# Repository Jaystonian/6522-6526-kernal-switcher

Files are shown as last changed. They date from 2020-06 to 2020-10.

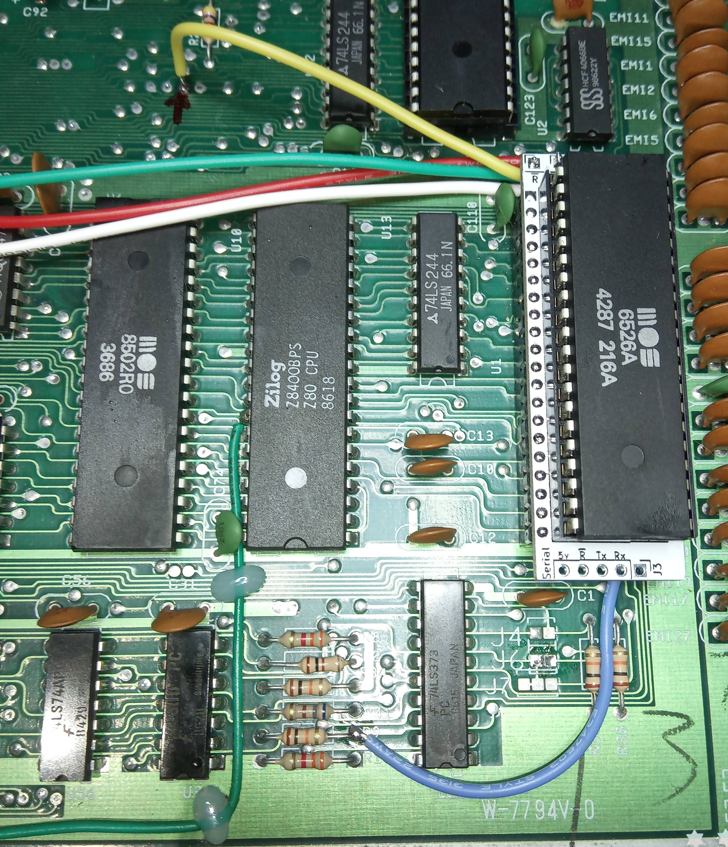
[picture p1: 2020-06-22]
docs/pics/c128_installed.jpg

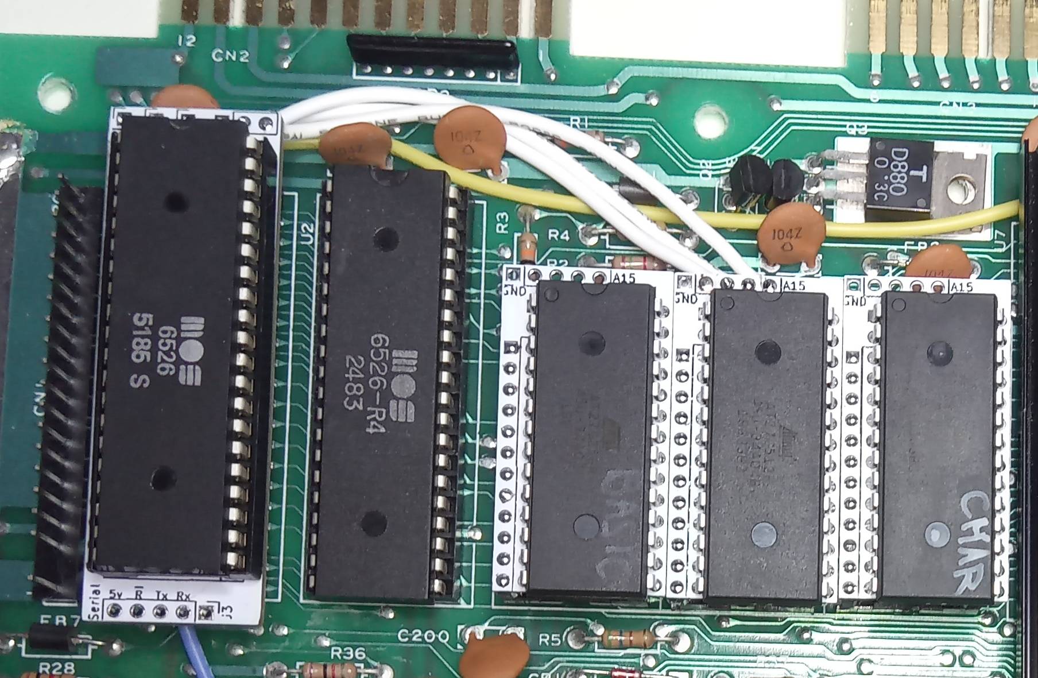
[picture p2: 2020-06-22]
docs/pics/c64_installed.jpg

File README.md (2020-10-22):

# 6522-6526-kernal-switcher
Adaptation of Sven Petersen's Keyboard Kernal Switch for MOS6522 or MOS6526 (VIC-20, C64, C128)

An ATMEGA328P microcontroller connected to the keyboard wires to listen for changes to keypresses 
of most of the top row of the keyboard. Hold down a number key and press RESTORE, (VIC-20 has 
limited compatibility) and three output bits (A B & C) for system control can be toggled by code.
The LED and bottom jumper can be wired directly (behind the resistor from the LED pin for example) 
and reprogrammed to use those as two extra output bits. Inputs can be reprogrammed to include + 
and - for example and then increase/decrease the selected output to control multiple EPROMs or 
devices for different reboot modes.  Memory controller modes, other ROMs, better control over more 
function roms in a C128 with more KERNAL ROMs (2 and 4 or 4 and 2 work well together with just ABC)
or memory maps etc.  With 5 you can dedicate 2 and 3 (giving 4 and 8 selections) instead of sharing 
lines as demonstrated in the C128 installation.

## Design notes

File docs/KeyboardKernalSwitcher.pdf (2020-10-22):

## Sven Petersen's C64-Keyboard-Controller-Kernal-Switch

https://github.com/svenpetersen1965/C64-Keyboard-Controlled-Kernal-Switch Jaystonian's 6522/6526 Version for VIC-20, C64, C128

I redesigned Sven's microcontroller board for higher compatibility. It originally only fit the C64 keyboard 20-SIP header connector, and some boards required other modifications. It resets the system after selecting different regions of an EPROM (such as the KERNAL) by selecting the higher address lines using the Restore key and a number. It also allows for “shortboard” eprom selecting, since
BASIC and KERNAL were combined in these models, with a solderjumper to tell the microcontroller.

It made sense to make it for the 40-DIP socket instead, so any system using the identical keyboard array can use the same switch. My idea is this can also be used to select configurations of the VIC-20's memory map, or different ROMs in different sockets on the C128 (KERNALs, BASICs, Internal EPROM socket). Also available on the C128 are data lines indicating 40/80 column mode and 64/128 mode. The 3 digital outputs of this switchboard provide a binary 0-7 (000-111, digital lines A, B and C). The solderjumper for shortboards in my design is called JP1, found on the bottom. I didn't include the JTAG connector or the full parts for the serial connection, although pins are exposed.

Please read and re-read instructions until steps are clear to you. Review the notes at the end of this document for advice on finding /RESTORE and /EXROM locations for your device model.

The six solder through-holes along the top end (between Pin 1 and Pin 40) are for /RESTORE, /EXROM, Power LED, and A B C. The serial connection straddles Pin 20 and Pin 21 (lower end); pins are 5V, /RESET, Tx, Rx and GND, respectively. Pin 1 (square pad) is GND. For the JTAG, 5V /RESET and GND are shared from serial, while MISO MOSI and SCK (respectively) are exposed as solderpads on the bottom, with MISO closest to Pin 40. For the most part, you will never need these.

We can use line A connected to the highest address line of a 27128 (16kb eprom) to select low/high 8kb for standard kernal or another, or the highest address line of a 27256 (32kb) for low/high 16kb regions. Or A and B for four, or A B C for eight. Hopefully this is not new information. This leads to multiple EPROMs, where C can be a low/high for the “Internal” socket, and A and B for kernal socket(s), and B for basic socket(s). This can provide a wider range of options for selecting EPROM regions.

For the more talented, you may choose to implement a selector circuit to configure eight completely different modes of any configuration for multiple EPROMs, enable memory expansions, toggle CPU speed... your imagination is the limit!

TOOLS NEEDED:
– Soldering iron
– Wire stripper (or whatever tool you are comfortable doing this with, without damaging the wire)
– Wire cutters
– Digital Multi Meter (DMM) or continuity tester

CONSUMABLES
– Solder and flux
– Some wire, 20ga to 26ga should be fine, solid or stranded, copper or not, shielded or not, but insulated always. If shielded, then be sure to ground the shielding and that it is not electrically connected.

INSTALLATION

1. Identify and locate the MOS 6522 or MOS 6526 40-pin IC chip responsible for your keyboard. This is typically U1 in 64/128, UAB1 or UDE8 (E) or UAB3 (CR) in VIC-20.
2. If this IC is not socketed, please de-solder it and then install a socket.
3. If you are installing this in a C64 shortboard (Rev 250469), then solder closed JP1 on the bottom. This is /SHORTBRD input in Sven's PDF, aka solderjumper “CP1”.
4. Locate the /RESTORE line on the motherboard and its distance to Pin 1 of the keyboard IC socket and then cut a wire long enough to reach, giving you an extra inch or two to trim later if necessary. Trim 1/8-inch of insulation from the wire and solder to the top-left through-hole of the switchboard.
5. Locate the /EXROM line on the motherboard and do the same as step 3 above, cutting a wire long enough, trim, then solder to the through-hole next to /RESTORE. This can be omitted on the VIC-20.
6. Optionally you may wire the Power LED directly to the third hole (anode of LED), which is current-limited by a 330-Ohm resistor on board, and then ground the LED's cathode. The switcher will flash this LED depending on modes. This is called RESIO in Sven's PDF.
7. The last three holes, which fits a 1x03 0.1” pitch (2.54mm) header, are A B C. For most users, you will have a single EPROM and ABC will go to A13, A14 and A15 of a 27512 for selecting one of eight 8KB regions, or you will be using shortboard mode (please review Sven's documentation for this). Or A15, A16 and A17 for 32KB regions of a 27c020 in a 32-pin socket. Or use your imagination!
8. Install switch board into socket with respect to “Pin 1 notch”, do not install backwards. The board has a socket with a notch on one end which should match the location of the socket notch underneath. Ensure your soldered wires do not contact anything else connected to the motherboard.
9. Solder /RESTORE and /EXROM wires to their respective locations on the motherboard. Ensure they are not soldered to more than one pin or location (resistor legs, vias, etc) and trim them short.
10. Install the 6522 or 6526 IC on top of the switch board, paying attention to the location of the Pin 1 notch.

USAGE

Please review Sven's original documentation. However, I will summarize:

While computer is ON...

– Holding RESTORE key for 1.5 to 3.0 seconds, you get a NORMAL RESET.
– Holding RESTORE ket for longer than 3.0 seconds, UNSTOPPABLE RESET.
– RESTORE + 0 selects 000 KERNAL and disables the scanning for improved compatibility (for diagnostic cartridges, for example)
– RESTORE + # (ie., 1 to 8, or 1 to 7 in shortboards) selects 000 to 111 KERNAL

NOTES

- VIC-20:
– /RESTORE can be found as the north leg of R1, south of U1 (whichever is not 5V)
– /EXROM does not exist, omit connection.
– Some of the number keys do not respond with the restore-reset and the ones that do just tend to randomly toggle the outputs and succeed a reset. No troubles if just switching two ROMs.
- VIC-20E:
– /RESTORE can be found as the north leg of R26, west of UD6
– /EXROM does not exist, omit connection.
- VIC-20CR:
– /RESTORE can be found as R16 south of the keyboard header. You will need to continuity test to find which leg, from Pin 3 of the keyboard header.
– /EXROM does not exist, omit connection.
- C64 Rev326298:
– /RESTORE can be found as the east leg of R41, along the west side of the board.
– /EXROM can be found on Pin 23 of U17. Continuity exploration recommended for a nearby through-hole between U17 and the SID chip.

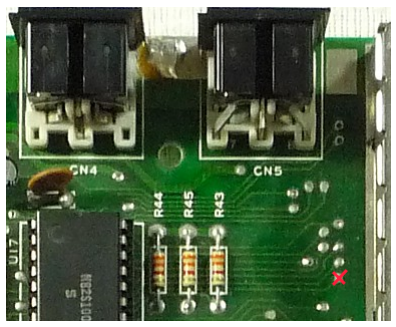
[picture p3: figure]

- C64 Rev250407:
– /RESTORE can be found as the east leg of R41, near the lower left corner of the board.
– /EXROM can be found south of the A/V Port, next to the RFM shield.

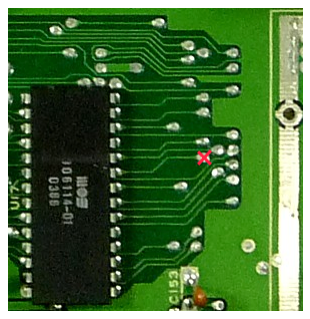
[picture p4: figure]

- C64 Rev250425:
– /RESTORE can be found as the east leg of R41, near the bottom-left corner of the board.
– /EXROM can be found right of U17

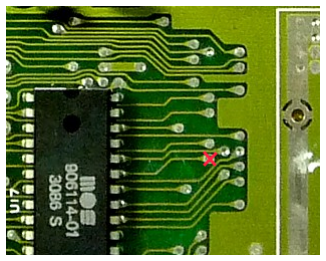
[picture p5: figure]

- C64 Rev250466:
– /RESTORE can be found as the east leg of R41, near the lower left corner of the board.
– /EXROM can be found east of U17
- C64 Rev250469:
– /RESTORE can be found immediately to the right of Keyboard Header pin 3.
– /EXROM can be found west of the RFM
- C128, 128D:

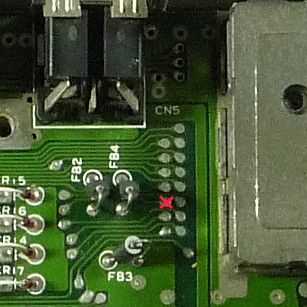
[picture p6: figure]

– /RESTORE is nearby U1, either immediately south near its Pin 21 (which would be beneath the installed switchboard), or the east leg of R9.
– /EXROM is to the left of U7, about 1/4-inch (~6mm) southwest of R27.

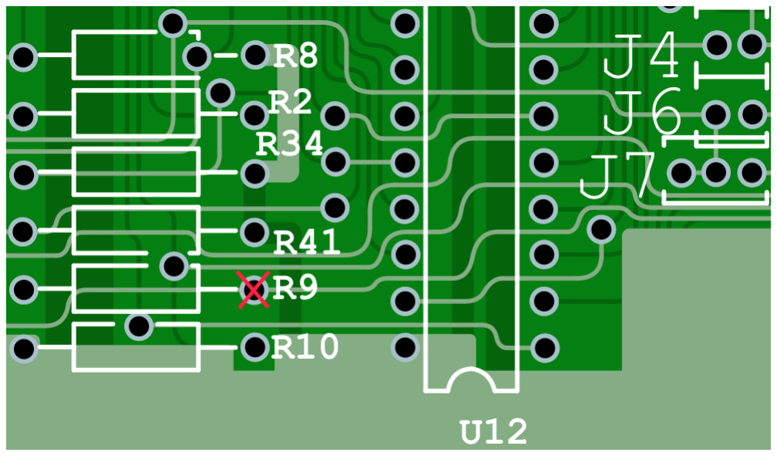
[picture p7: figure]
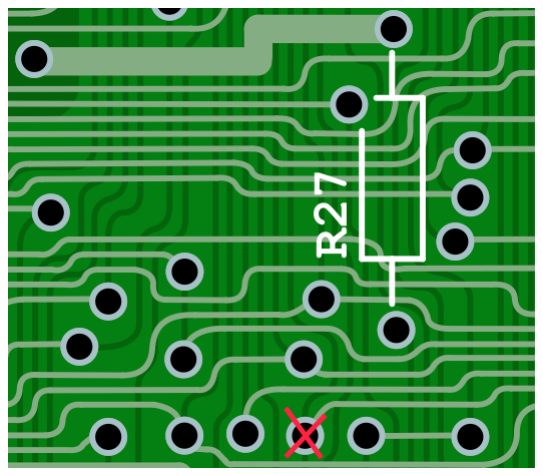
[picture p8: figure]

- C128DCR: There are several revisions of this Cost Reduced model. I have an earlier model that is a “full-size board.” The simplest way for you to find exposed through-holes, instead of IC legs, is with a continuity tester using the leg pin as a starting point and then explore.
– /RESTORE can be found on Pin 9 of U16
– /EXROM can be found on Pin 46 of U7

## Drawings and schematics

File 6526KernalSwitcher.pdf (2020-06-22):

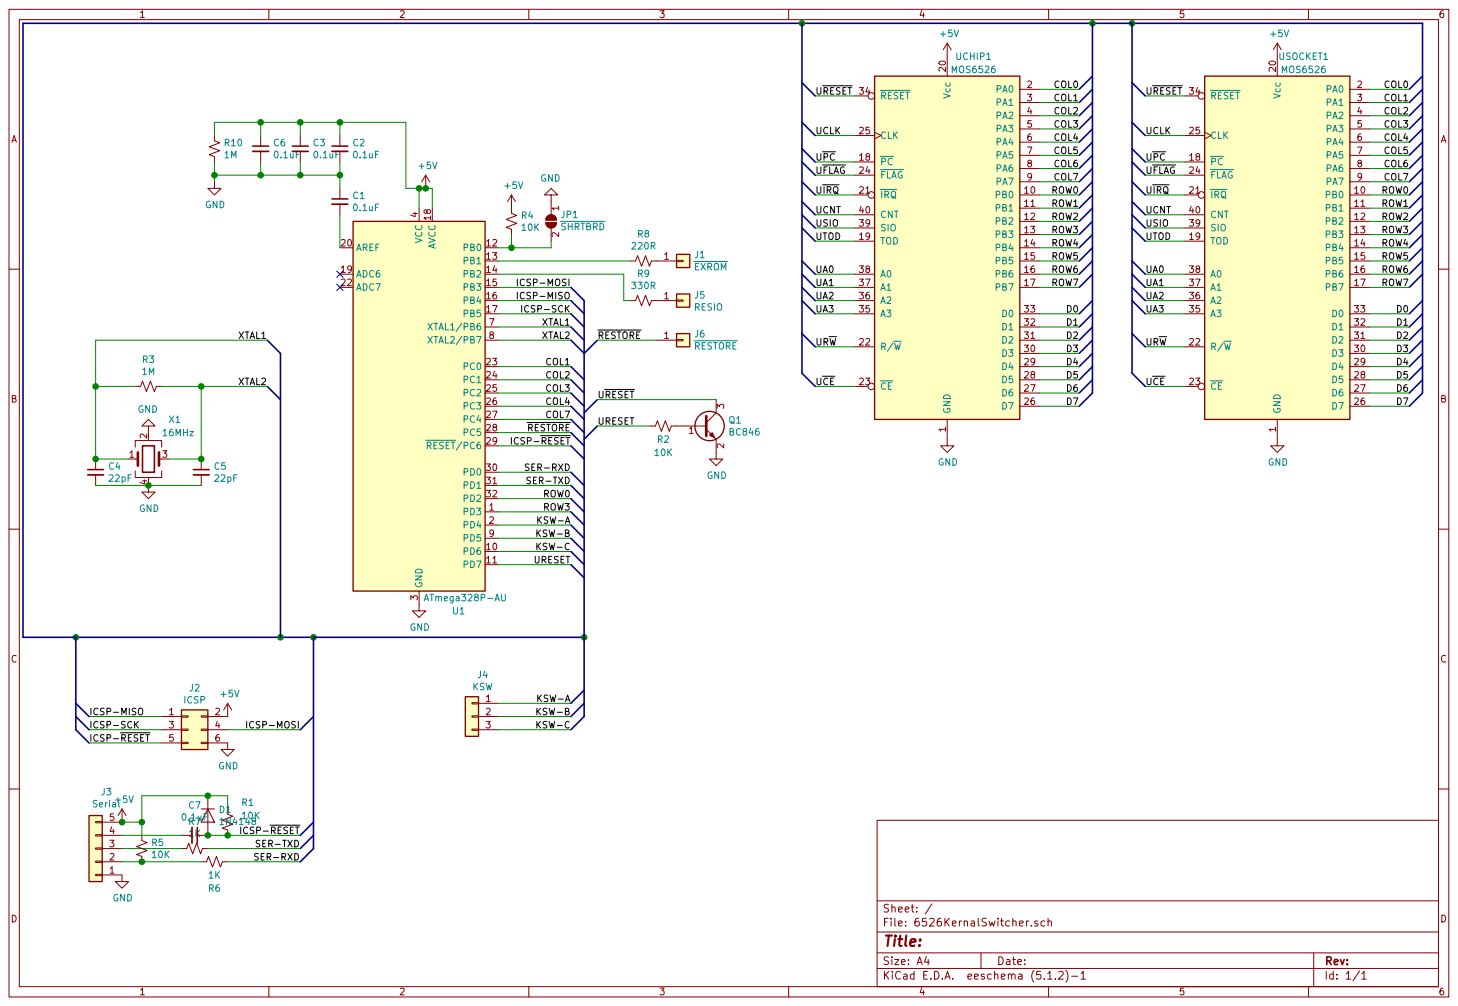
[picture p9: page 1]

ICSP-RESET SER-TXD

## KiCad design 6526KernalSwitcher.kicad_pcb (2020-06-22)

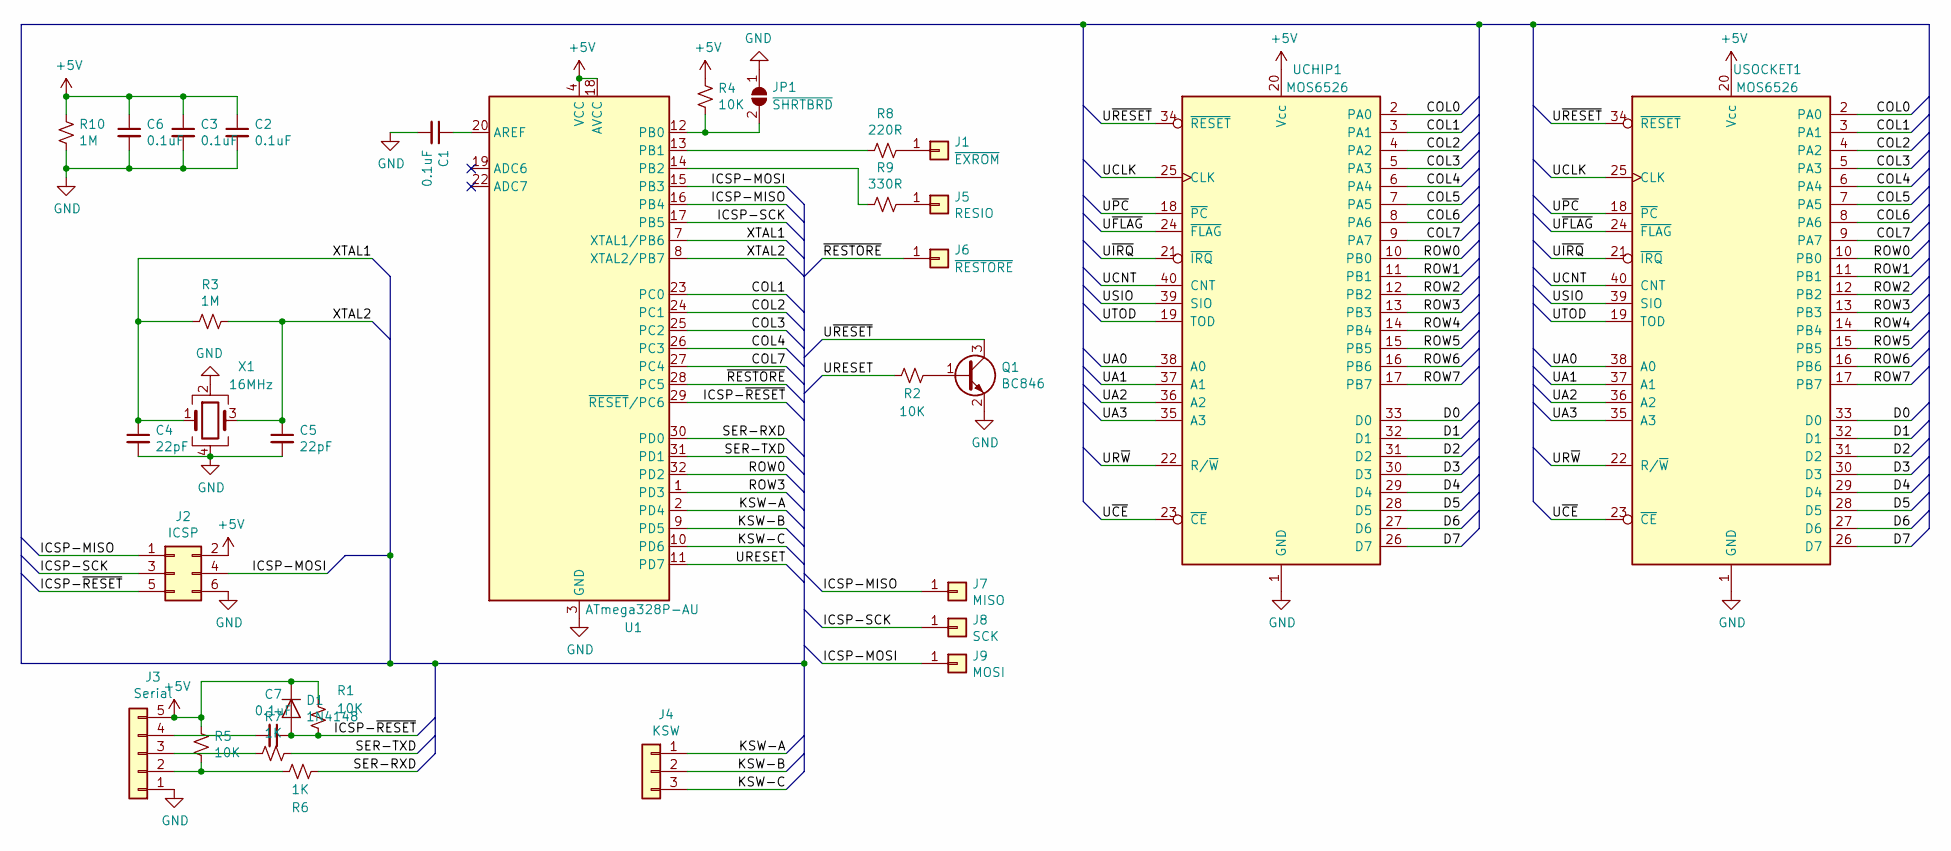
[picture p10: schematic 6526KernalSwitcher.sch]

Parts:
C1, C2, C3, C6, C7: 0.1uF; C_0805_2012Metric_Pad1.15x1.40mm_HandSolder
C4, C5: 22pF; C_0805_2012Metric_Pad1.15x1.40mm_HandSolder
D1: 1N4148; D_MiniMELF
J1: ~EXROM; PinHeader_1x01_P2.54mm_Vertical
J2: ICSP; PinHeader_2x03_P2.54mm_Vertical
J3: Serial; PinHeader_1x05_P2.54mm_Vertical
J4: KSW; PinHeader_1x03_P2.54mm_Vertical
J5: RESIO; PinHeader_1x01_P2.54mm_Vertical
J6: ~RESTORE; PinHeader_1x01_P2.54mm_Vertical
J7: MISO; SolderPad
J8: SCK; SolderPad
J9: MOSI; SolderPad
JP1: ~SHRTBRD; SolderJumper-2_P1.3mm_Open_RoundedPad1.0x1.5mm
Q1: BC846; SOT-23
R1, R2, R4, R5: 10K; R_0805_2012Metric_Pad1.15x1.40mm_HandSolder
R3, R10: 1M; R_0805_2012Metric_Pad1.15x1.40mm_HandSolder
R6, R7: 1K; R_0805_2012Metric_Pad1.15x1.40mm_HandSolder
R8: 220R; R_0805_2012Metric_Pad1.15x1.40mm_HandSolder
R9: 330R; R_0805_2012Metric_Pad1.15x1.40mm_HandSolder
U1: ATmega328P-AU; TQFP-32_7x7mm_P0.8mm
UCHIP1: MOS6526; DIP-40_W15.24mm
USOCKET1: MOS6526; DIP-40_W15.24mm
X1: 16MHz; Crystal_SMD_2016-4Pin_2.0x1.6mm

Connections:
+5V: C2.1, C3.1, C6.1, D1.1 (K), J2.2, J3.5, R1.1, R4.1, R5.1, R10.1, U1.4 (VCC), U1.6 (VCC), U1.18 (AVCC), UCHIP1.20 (Vcc), USOCKET1.20 (Vcc)
/COL0: UCHIP1.2 (PA0), USOCKET1.2 (PA0)
/COL1: U1.23 (PC0), UCHIP1.3 (PA1), USOCKET1.3 (PA1)
/COL2: U1.24 (PC1), UCHIP1.4 (PA2), USOCKET1.4 (PA2)
/COL3: U1.25 (PC2), UCHIP1.5 (PA3), USOCKET1.5 (PA3)
/COL4: U1.26 (PC3), UCHIP1.6 (PA4), USOCKET1.6 (PA4)
/COL5: UCHIP1.7 (PA5), USOCKET1.7 (PA5)
/COL6: UCHIP1.8 (PA6), USOCKET1.8 (PA6)
/COL7: U1.27 (PC4), UCHIP1.9 (PA7), USOCKET1.9 (PA7)
/D0: UCHIP1.33 (D0), USOCKET1.33 (D0)
/D1: UCHIP1.32 (D1), USOCKET1.32 (D1)
/D2: UCHIP1.31 (D2), USOCKET1.31 (D2)
/D3: UCHIP1.30 (D3), USOCKET1.30 (D3)
/D4: UCHIP1.29 (D4), USOCKET1.29 (D4)
/D5: UCHIP1.28 (D5), USOCKET1.28 (D5)
/D6: UCHIP1.27 (D6), USOCKET1.27 (D6)
/D7: UCHIP1.26 (D7), USOCKET1.26 (D7)
/ICSP-MISO: J2.1, J7.1, U1.16 (PB4)
/ICSP-MOSI: J2.4, J9.1, U1.15 (PB3)
/ICSP-SCK: J2.3, J8.1, U1.17 (PB5)
/ICSP-~RESET: C7.1, D1.2 (A), J2.5, R1.2, U1.29 (~RESET~/PC6)
/KSW-A: J4.1, U1.2 (PD4)
/KSW-B: J4.2, U1.9 (PD5)
/KSW-C: J4.3, U1.10 (PD6)
/ROW0: U1.32 (PD2), UCHIP1.10 (PB0), USOCKET1.10 (PB0)
/ROW1: UCHIP1.11 (PB1), USOCKET1.11 (PB1)
/ROW2: UCHIP1.12 (PB2), USOCKET1.12 (PB2)
/ROW3: U1.1 (PD3), UCHIP1.13 (PB3), USOCKET1.13 (PB3)
/ROW4: UCHIP1.14 (PB4), USOCKET1.14 (PB4)
/ROW5: UCHIP1.15 (PB5), USOCKET1.15 (PB5)
/ROW6: UCHIP1.16 (PB6), USOCKET1.16 (PB6)
/ROW7: UCHIP1.17 (PB7), USOCKET1.17 (PB7)
/SER-RXD: R6.1, U1.30 (PD0)
/SER-TXD: R7.1, U1.31 (PD1)
/UA0: UCHIP1.38 (A0), USOCKET1.38 (A0)
/UA1: UCHIP1.37 (A1), USOCKET1.37 (A1)
/UA2: UCHIP1.36 (A2), USOCKET1.36 (A2)
/UA3: UCHIP1.35 (A3), USOCKET1.35 (A3)
/UCLK: UCHIP1.25 (CLK), USOCKET1.25 (CLK)
/UCNT: UCHIP1.40 (CNT), USOCKET1.40 (CNT)
/URESET: R2.2, U1.11 (PD7)
/UR~W: UCHIP1.22 (R/~W~), USOCKET1.22 (R/~W~)
/USIO: UCHIP1.39 (SIO), USOCKET1.39 (SIO)
/UTOD: UCHIP1.19 (TOD), USOCKET1.19 (TOD)
/U~CE: UCHIP1.23 (~CE~), USOCKET1.23 (~CE~)
/U~FLAG: UCHIP1.24 (~FLAG~), USOCKET1.24 (~FLAG~)
/U~IRQ: UCHIP1.21 (~IRQ~), USOCKET1.21 (~IRQ~)
/U~PC: UCHIP1.18 (~PC~), USOCKET1.18 (~PC~)
/U~RESET: Q1.3 (C), UCHIP1.34 (~RESET~), USOCKET1.34 (~RESET~)
/XTAL1: C4.1, R3.2, U1.7 (XTAL1/PB6), X1.1
/XTAL2: C5.1, R3.1, U1.8 (XTAL2/PB7), X1.3
/~RESTORE: J6.1, U1.28 (PC5)
GND: C1.2, C2.2, C3.2, C4.2, C5.2, C6.2, J2.6, J3.1, JP1.1 (A), Q1.2 (E), R10.2, U1.3 (GND), U1.5 (GND), U1.21 (GND), UCHIP1.1 (GND), USOCKET1.1 (GND), X1.2, X1.4
unnamed: C1.1, U1.20 (AREF)
unnamed: C7.2, J3.4
unnamed: J1.1, R8.1
unnamed: J3.2, R5.2, R6.2
unnamed: J3.3, R7.2
unnamed: J5.1, R9.1
unnamed: JP1.2 (B), R4.2, U1.12 (PB0)
unnamed: Q1.1 (B), R2.1
unnamed: R8.2, U1.13 (PB1)
unnamed: R9.2, U1.14 (PB2)

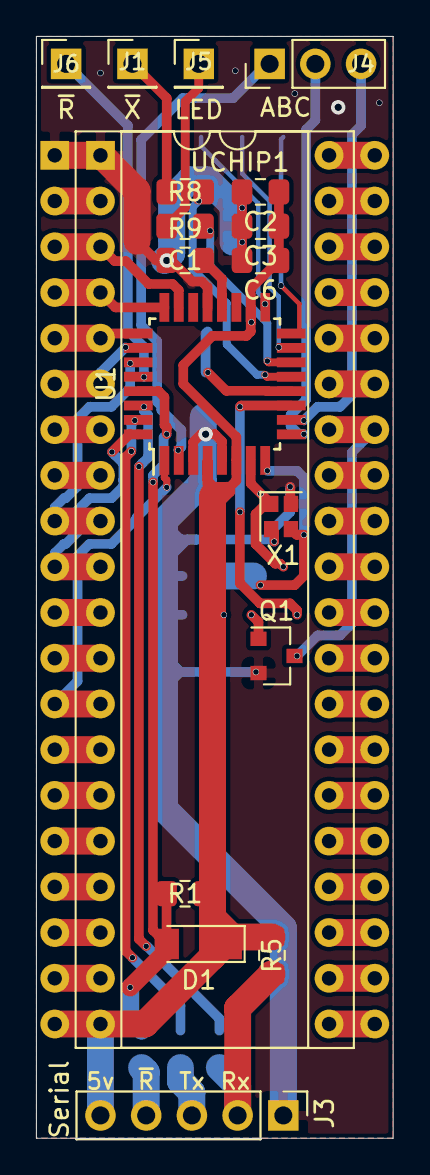
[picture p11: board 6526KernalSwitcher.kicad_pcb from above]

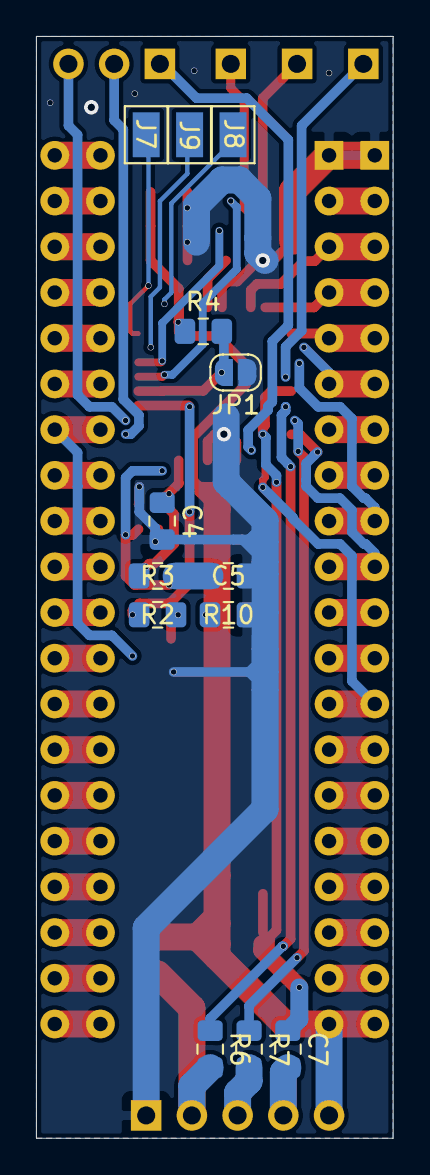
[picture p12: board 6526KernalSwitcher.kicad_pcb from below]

Board: 2 copper layers, 19.8 x 61.2 mm, 32 parts (13 on the bottom side), 63 nets.

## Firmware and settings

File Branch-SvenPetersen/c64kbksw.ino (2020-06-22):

/*  Software for the keyboard controlled kernal switch
 *  by Sven Petersen, 2020
 *  
 *  Revisioon history 
 *  Rev. 0.0: initial release
 *  Rev. 0.1: since some games (e.g. Gyruss) modify the reset procedure, the "unstoppable reset" (= EXROM Reset) was 
 *            implemented. Pressing RESTORE for approximatety 2-4 seconds is a normal reset, holding it longer =  
 *            EXROM reset.
 *  Rev. 0.2: Implemented signalling on RESIO2.          
 */

#define LED
//#define buzzer

#include <EEPROM.h>

/* Configuration */
const bool recover_empty = true;     //enable recover to Kernal one, in case an empty/not working kernal was selected
const int  NumKernal = 8;            //This is the highest valid Kernal number
 
/* pin definitions */
const int row0 = 2;         // Row signal, input, active low, INT0
const int row3 = 3;         // Row signal, input, active low, INT1
const int KSW_A13 = 4;      // output, A13 to kernal adaptor/switch
const int KSW_A14 = 5;      // output, A14 to kernal adaptor/switch
const int KSW_A15 = 6;      // output, A15 to kernal adaptor/switch
const int C64RESET = 7;     // output, RESET signal for the C64
const int col1 = A0;        // input, column signal, active low
const int col2 = A1;        // input, column signal, active low
const int col3 = A2;        // input, column signal, active low
const int col4 = A3;        // input, column signal, active low
const int col7 = A4;        // input, column signal, active low
const int nRESTORE = A5;    // input, RESTORE key, active low
const int nSHORT_BRD = 8;   // input, short board jumper
const int nEXROM = 9;       // /EXROM Pin connected to pin header J4, pin 5 
// const int RSVD  = 10;    // reserved. Pin connected to pin header J4, pin 6
const int Signalling  = 10; // Pin for signaling (LED or buzzer with tone generator), pin header J4, pin 6

#ifdef buzzer
const bool sig_idle = LOW;   // idle level of J4, pin 6 (should be HIGH for a power LED) 
#else
const bool sig_idle = HIGH;  // idle level of J4, pin 6 (should be HIGH for a power LED)
#endif 

const int Restore_Count = 1500; // count appr. 2 seconds for RestoreKey before Reset
const int EXROM_Count = 3000;   // limit for EXROM reset
const int Sig_time = 500; // constant for signalling duration

/* other constants */
#define EEPROMAddr 0        // EEPROM Address of last kernal selection
#define ScanDelay 10000     // delay ibn ms before reset for no scan activity or an empty kernal memory slot, respectively

/* variables */
byte KOffset = 0;           // offset for kernal number
byte KNumber = 0;           // Kernal number
byte KAddr = 0;             // Address bits for Kernal
bool RestoreKey = 0;        // holds the info, if the restore key is pressed 
bool oldRestoreKey = 0;     // remeber the old status to compare
int  countup = 0;           // counter for restore key time measurement
byte key = 128;             // calculate the Key
int  KMax;                  // holds the highest Kernal Number


/* Data Exchange variables for ISR (have to be volatile) */
volatile bool NumPressed = 0;  // ISR flag for number pressed
volatile bool NumOdd = 0;      // ISR flag for odd numbers. Row0 => odd numbers, Row3 => even numbers
volatile byte ColData = 0x1F;  // column data, read from PORTD

/* in case, the kernal switch switches to a memory slot without a proper kernal software
 *  there is no keyboard scan activity. That is why the kernal switch cannot detect keys anymore
 *  to circumvent this, the column scan activity is detected. If there is no activity after switching kernals
 *  the kernal is set to #1 and the C64 is reset.
 */
byte columns;           // variable for reading out the column
int scan_cnt;           // 5000 miliseconds without scan changing to kernal #1 and resetting
int scan_found;         // flag for keybioard activity detected
byte inactive = 0;      // keyboard scan inactive: 1 -> inactive, 0 = active
bool exrom_mode = 0;    // exrom reset: 0 => no, 1 => yes
int signalling_cnt = 0; // count down for signalling pin

void setup() {
  /* keyboard scan signals */
  pinMode( row0, INPUT_PULLUP);  // pullup required for MOS logic
  pinMode( row3, INPUT_PULLUP);  // pullup required for MOS logic
  pinMode( col1, INPUT_PULLUP);  // pullup required for MOS logic
  pinMode( col2, INPUT_PULLUP);  // pullup required for MOS logic
  pinMode( col3, INPUT_PULLUP);  // pullup required for MOS logic
  pinMode( col4, INPUT_PULLUP);  // pullup required for MOS logic
  pinMode( col7, INPUT_PULLUP);  // pullup required for MOS logic
  pinMode( nRESTORE, INPUT_PULLUP);  // pullup required for MOS logic
  pinMode( nEXROM, INPUT );      // it needs to be high impedance, will switch to LOW and OUTPUT when required.
  digitalWrite( nEXROM, HIGH );
  digitalWrite( Signalling, sig_idle ); // Signalling pin6, J4
  pinMode( Signalling, OUTPUT);

  /* jumper */
  pinMode(nSHORT_BRD, INPUT);   // jumper: LOW = Short Board => lowest kernal number is 1
  if (digitalRead(nSHORT_BRD) == LOW)
  { 
    KOffset = 1; // it is a short board! kernal number offset is 1, since the BASIC is in the lowest 8k of the Kernal ROM
  }

  /* last kernal from eeprom */
  KNumber = EEPROM.read(EEPROMAddr);
  if ((KNumber < 1) || (KNumber > 8-KOffset)) { // if out of range, the first kernal is selected.
    KNumber = 1;
    EEPROM.write(EEPROMAddr, KNumber);
  }
  inactive = EEPROM.read(EEPROMAddr+1);         // keyscan inactive flag
  if (inactive > 1) {
    inactive = 0;
    EEPROM.write(EEPROMAddr+1, inactive);
  }
  exrom_mode = 0;                               // initialize exrom mode (for reset). 0 = no exrom reset
  
  KAddr = KNumber - 1 + KOffset; // Calculate the address bits.
  // For long boards, it should be between 0 and 7,
  // for short boards, it should be 1 to 7, because the first 8k are occupied by the BASIC ROM. 
  
  /* Control outputs (for Kernal Adaptor and C64) */
  SetAddressBits( KAddr );        // set the MS address bits for the kernal ROM
  pinMode( KSW_A13, OUTPUT );     // make it an output   
  pinMode( KSW_A14, OUTPUT );     // make it an output
  pinMode( KSW_A15, OUTPUT );     // make it an output
  digitalWrite( C64RESET, LOW );  // no reset for the C64
  pinMode( C64RESET, OUTPUT );    // make it an output

  if (recover_empty == true) {
    scan_cnt = ScanDelay;         // reset scan countdown
    scan_found = false;           // reset detection flag 
    KMax = 8 - KOffset; 
  }
  else {
    scan_cnt = 0;                 // reset scan countdown
    scan_found = true;            // reset detection flag
    KMax = NumKernal;
  }
  if (inactive == 1) {             // if scan timeout is inactive, just set scan_found
    scan_found = true;
    scan_cnt = 0;
  }
      
  attachInterrupt(digitalPinToInterrupt(row0), ISR_row0, LOW); 
  attachInterrupt(digitalPinToInterrupt(row3), ISR_row3, LOW);
  
  Serial.begin(9600);  // start serial interface
  /* output status etc. */
  Serial.println( "\nC64 Keyboard Controlled Kernal Switch v0.20" );
  if (KOffset == 1) {
    Serial.println("Short Board configured.");
  }
  else {
    Serial.println("Long Board configured.");
  }
  if (recover_empty == true) {
    Serial.print("Empty Kernal slot (=scan activity) detection: ");
    if (inactive == 1 ) {
      Serial.println("inactive.");
    }
    else {
      Serial.println("active.");
    }
  }
  else {
    Serial.print("Number of Kernals: ");
    Serial.println(NumKernal);
  }
  Serial.print("Kernal number: ");
  Serial.println( KNumber );
}

/* This function sets the address bits on the pin header J4. Parameter is addr (0..7) */
void SetAddressBits( byte addr ) {
   digitalWrite( C64RESET, HIGH );                              // do it, while /reset is low (samle like the port pin is high)
   delay (50 );                                                 // wait 50 ms
   if ((addr & 1) == 0) {         // A13                  
    digitalWrite(KSW_A13, LOW);
  }
  else {
    digitalWrite(KSW_A13, HIGH);  
  }
  if ((addr & 2) == 0) {          // A14
    digitalWrite(KSW_A14, LOW);
  }
  else {
    digitalWrite(KSW_A14, HIGH);  
  }
  if ((addr & 4) == 0) {          // A15
    digitalWrite(KSW_A15, LOW);
  }
  else {
    digitalWrite(KSW_A15, HIGH);  
  }
}

void ResetC64() {
  digitalWrite( Signalling, !sig_idle );                     // Signalling active
  digitalWrite( C64RESET, HIGH );                            // issue a reset pulse for the C64
  delay( 100 );                                              // 100ms delay
  if (exrom_mode == 1) {
    digitalWrite( nEXROM, LOW );                             // exrom pin low
    pinMode( nEXROM, OUTPUT );                               // and output
  }
  delay( 300 );                                              // pulse duration: 100+300ms
  digitalWrite( C64RESET, LOW );
  if (exrom_mode == 1) {
    delay( 300 );                                            // EXROM should be 300ms longer LOW than RESET
    pinMode( nEXROM, INPUT );                                // and input = high impedance (HIZ)
    digitalWrite( nEXROM, HIGH );                            // exrom pin high
  }
  if ((recover_empty == true) && (inactive == 0)) {
    scan_cnt = ScanDelay;                                    // reset scan countdown
    scan_found = false;                                      // reset detection flag
  }  
  else {
    scan_cnt = 0;
    scan_found = true;
  }
  countup = 0;
  digitalWrite( Signalling, sig_idle );                      // Signalling inactive
}

void SwitchKernal() {
  digitalWrite( C64RESET, HIGH );                            // issue a reset pulse for the C64
  SetAddressBits( KAddr );                                   // set the address bits A15..A13
  Serial.print("Change to Kernal number: ");                 // send the status to serial
  Serial.println( KNumber );
  ResetC64();                                                // Reset the C64
  delay( 2000 );                                             // give some delay to release the RESTORE key
}

// Interrupt Service Routine for Row0
void ISR_row0() {
  if (NumPressed == 0) {                  // only process info, after the flag was reset by main routine
     ColData = PINC & 0x1F;               // read the columns
     scan_found = true;                   // any activity here indicates a working kernal
     NumOdd = 1;                          // row0 has the odd numbers
     if ((ColData != 0x1F) && (ColData !=0)) {               // only set the flag, when a number is pressed 
       NumPressed = 1;
     }  
  }
}

// Interrupt Service Routine for Row3
void ISR_row3 () {
  if (NumPressed == 0) {                  // only process info, after the flag was reset by main routine
     ColData = PINC & 0x1F;               // read the columns
     scan_found = true;                   // any activity here indicates a working kernal
     NumOdd = 0;                          // row3 has the even numbers
     if ((ColData != 0x1F) && (ColData !=0)) { // only set the flag, when a number is pressed 
       NumPressed = 1;
     }  
  }
}

void loop() {
  /* find the scan activity to make sure, the selected Kernal is working */
  if (scan_found == false) {                            // if not yet a scan activity is detected
    columns = PINC & 0x1F;                              // read the column data
    if ((columns != 0x1F)) {                            // activity found?
      scan_found = true;                                // set flag
      Serial.println( "Keyboard scan detected."); 
    }
    else {
      if (scan_cnt > 0) {                               // if the count down is not elapsed
        scan_cnt--;                                     // then decrement
        delayMicroseconds( 33 );
      }
      else {
        Serial.println( "No keyboard scan detected.");  // the count down is elapsed!
        KNumber = 1;                                    // Set Kernal Number 1 (it is assumed, that this is not empty)
        EEPROM.write(EEPROMAddr, KNumber);              // and save in EEPROM
        KAddr = KOffset;                                // Calculate the address bits.
        SwitchKernal();                                 // Switch Kernal Number and reset C64
      }
    }
  }
  
  /* process restore key */ 
  if (digitalRead( nRESTORE ) == HIGH) {
     if (RestoreKey == 1) {                // now no RESTORE, but last status was RESTORE => Restore key released 
        if (countup > EXROM_Count) {       // is the limit for EXROM reset reached?
          exrom_mode = 1;
          Serial.print( "EXROM mode: ");
        }
        if (countup > Restore_Count) {
          Serial.println("Restore key => Reseting the C64");
          ResetC64();                      // RESET the C64
          exrom_mode = 0;
        }
     }
     RestoreKey = 0;                      // in case the reading is HIGH, the Restore key is not pressed
     countup = 0;                         // restart the count down
  }
  else {
    RestoreKey = 1;                       // in case the restore is pressed, count up
    countup++;
    if (countup == Restore_Count ) {
       digitalWrite( Signalling, !sig_idle );
       signalling_cnt = Sig_time;
    }
    if (countup > EXROM_Count) {          // time limit for EXROM reached?
       exrom_mode = 1;                    // activate EXROM mode
       Serial.println("EXROM mode: Restore key => Reseting the C64");
       ResetC64();                        // reset the C64
       RestoreKey = 0;                    // restart the restore key
       countup = 0;                       // restart the count down
       exrom_mode = 0;                    // reset EXROM mode
    }
  }
  if (signalling_cnt > 0) {
    if (--signalling_cnt == 0) {
      digitalWrite( Signalling, sig_idle );
    }
  }
  /* The ISR will set NumPressed to 1, in case some number key is pressed 
     In case something is found, the column data, which was read by the ISR 
     is being processed here.  
  */
  if (NumPressed == 1) {                     // if a number key is pressed: process the data
    if ((ColData & B00010000) == 0) {        // column 7: "1"
      key = 1;
    }
    else if ((ColData & B00000001) == 0) {   // column 1: "3"
      key = 3;
    }
    else if ((ColData & B00000010) == 0) {   // column 2: "5"
      key = 5;
    }
    else if ((ColData & B00000100) == 0) {   // column 3: "7"
      key = 7;
    }
    else if ((ColData & B00001000) == 0) {   // column 4: "9"
      key = 9;
    }
    /*
     * The even numbers are on row 3, the odd numbers are on row 1
     * NumOdd is set by the ISR
    */
    if (NumOdd == 0) {                       // the even number are higher by one
      key++;
    }
    if (key == 10) {                         // in case it is a "0" 
      key = 0;
    }
    Serial.print("Key ");
    Serial.print(key);
    Serial.println(" detected.");
    if ((key > 0) && (key < KMax+1) && (RestoreKey == 1)) {       // restore pressed and key in range
       KNumber = key;                                             // set Kernal Number
       EEPROM.write(EEPROMAddr, KNumber);                         // write it to the EEPROM
       KAddr = KNumber - 1 + KOffset;                             // Calculate the address bits. 
                                                                  // For long boards, it should be between 0 and 7,
                                                                  // for short boards, it should be 1 to 7, because the first 8k are occupied by the BASIC ROM. 
       inactive = 0;                                              // every valid kernal leaves inactive state
       EEPROM.write(EEPROMAddr+1, inactive);                      // write it to EEPROM
       SwitchKernal();                                            // Switch Kernal Number and reset C64
    }
    else if ((key == 0) && (RestoreKey == 1)) {                   // key "0" switches to kernal #1 and enters inactive state
      KNumber = 1;                                                // inactove means, that the initial key scan timeout is inactive
      EEPROM.write(EEPROMAddr, KNumber);                          // which is useful for catridges, that do not perform a keyboard scan
      KAddr = KNumber - 1 + KOffset;
      inactive = 1;                                               // enter inactive state
      EEPROM.write(EEPROMAddr+1, inactive);                       // write it to EEPROM
      Serial.println( "Kernal 1 and scan timeout inactive." );    // send to serial
      SwitchKernal();                                             // Switch Kernal Number and reset C64
    }
    else {
      key = 128;                                                  // reset the key number
    }
    NumPressed = 0;                                               // reset the flag, so the ISR can process key matrix again
  }
  else {
    key = 128;                                                    // reset the key number
  }
  delayMicroseconds( 1000 );                                      // delay 1ms per loop (not calibrated)
}
